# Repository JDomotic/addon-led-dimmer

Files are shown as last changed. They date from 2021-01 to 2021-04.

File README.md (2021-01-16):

# 9 Channel PWM Dimmer Addon
This is a custom made PWM dimmer addon which fits on the back of the [Wireless sensor board](https://github.com/JDomotic/esp12-wireless-sensor-board) .

The board can receive commands over uart with configurable transition speed per channel

## Version 1 | 05-01-2019
**Features**:
* Onboard 500ma 3.3v power regulator to power itself and the wireless sensor board
* Support for 12v led strips 
* 9 PWM channels 8 bit

**Schematic**

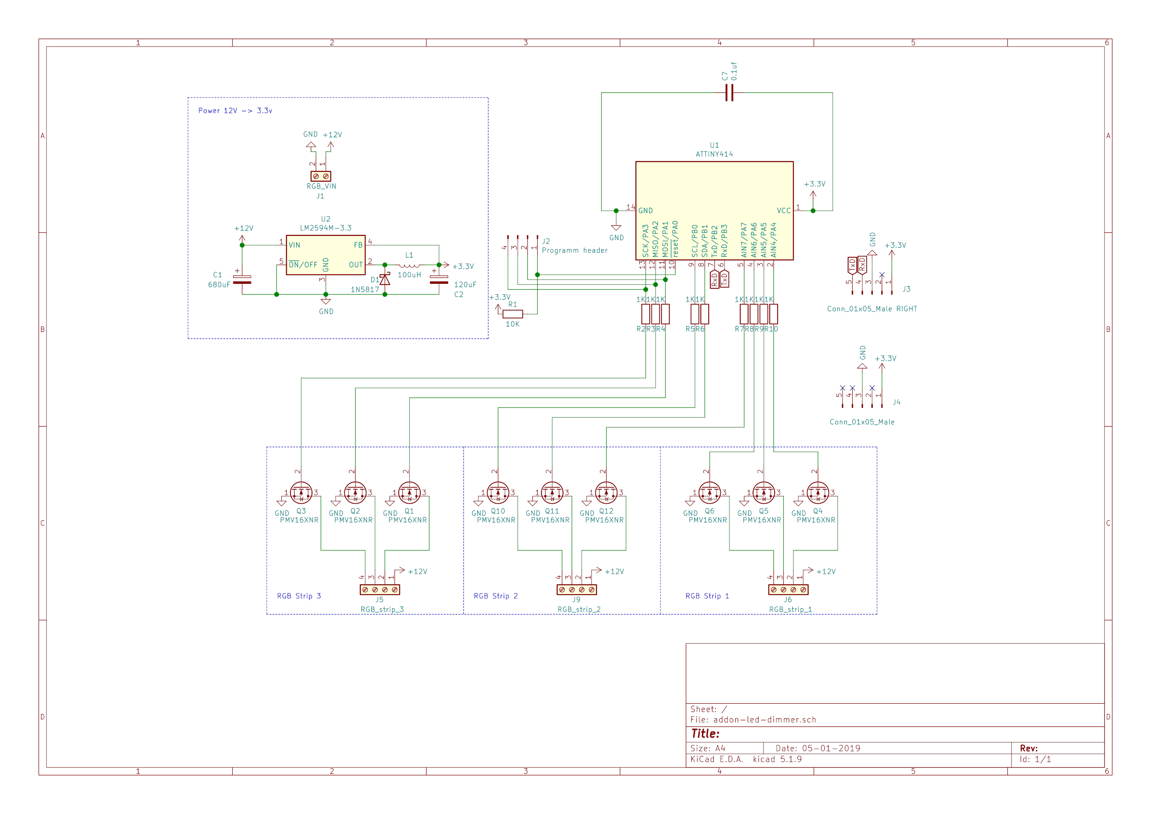
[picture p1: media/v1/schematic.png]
Schematic V1


**BOM**

**Ref**|**Qnty**|**Value**|**Footprint**|**Vendor (LCSC)**
:-----: | :-----: | :-----: | :-----: | :-----:
C1,|1|680uF|Capacitor\_THT:CP\_Radial\_D8.0mm\_P3.50mm|C59427|$0,0906
C2,|1|120uF|Capacitor\_THT:CP\_Radial\_D6.3mm\_P2.50mm|C251018|$0,1182
C7,|1|0.1uf|Capacitor\_SMD:C\_1206\_3216Metric\_Pad1.42x1.75mm\_HandSolder|C128353|$0,0179
D1,|1|1N5817|Diode\_THT:D\_DO-41\_SOD81\_P10.16mm\_Horizontal|C169165|$0,0223
J1,|1|RGB\_VIN|TerminalBlock\_Phoenix:TerminalBlock\_Phoenix\_MKDS-1,5-2\_1x02\_P5.00mm\_Horizontal|C8269|$0,0954
J3,|1|Conn\_01x05\_Male RIGHT|Connector\_PinHeader\_2.54mm:PinHeader\_1x05\_P2.54mm\_Vertical|-|0
J4,|1|Conn\_01x05\_Male|Connector\_PinHeader\_2.54mm:PinHeader\_1x05\_P2.54mm\_Vertical|-|0
J5,|2|RGB\_strip\_3|TerminalBlock\_Phoenix:TerminalBlock\_Phoenix\_MKDS-1,5-4\_1x04\_P5.00mm\_Horizontal|C8269|$0,1908
J6,|2|RGB\_strip\_1|TerminalBlock\_Phoenix:TerminalBlock\_Phoenix\_MKDS-1,5-4\_1x04\_P5.00mm\_Horizontal|C8269|$0,1908
J9,|2|RGB\_strip\_2|TerminalBlock\_Phoenix:TerminalBlock\_Phoenix\_MKDS-1,5-4\_1x04\_P5.00mm\_Horizontal|C8269|$0,1908
L1,|1|100uH|Inductor\_SMD:L\_6.3x6.3\_H3|C10122|$0,0731
Q1, Q2, Q3, Q4, Q5, Q6, Q10, Q11, Q12,|9|PMV16XNR|Package\_TO\_SOT\_SMD:SOT-23|C110920|$0,8064
R1,|1|10K|Resistor\_SMD:R\_0805\_2012Metric\_Pad1.15x1.40mm\_HandSolder|C103904|$0,0025
R2, R3, R4, R5, R6, R7, R8, R9, R10,|9|1K|Resistor\_SMD:R\_0805\_2012Metric\_Pad1.15x1.40mm\_HandSolder|C95781|$0,0360
U1,|1|ATTINY414|Package\_SO:SOIC-14\_3.9x8.7mm\_P1.27mm|C189365|$0,7137
U2,|1|LM2594M-3.3|Package\_SO:SOIC-8\_3.9x4.9mm\_P1.27mm|C316691|$0,6088

**Render**

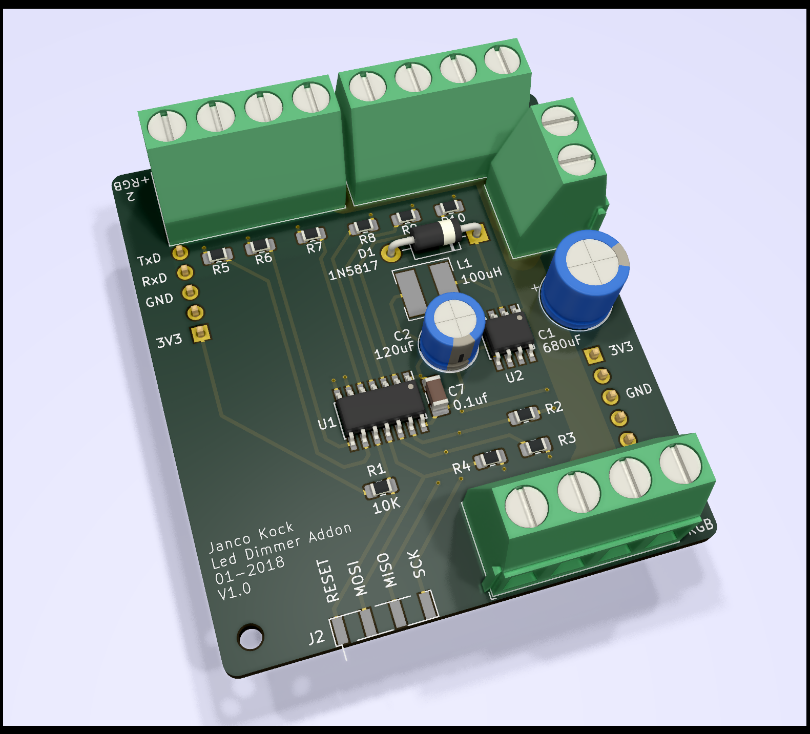
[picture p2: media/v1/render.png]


**Assembled**

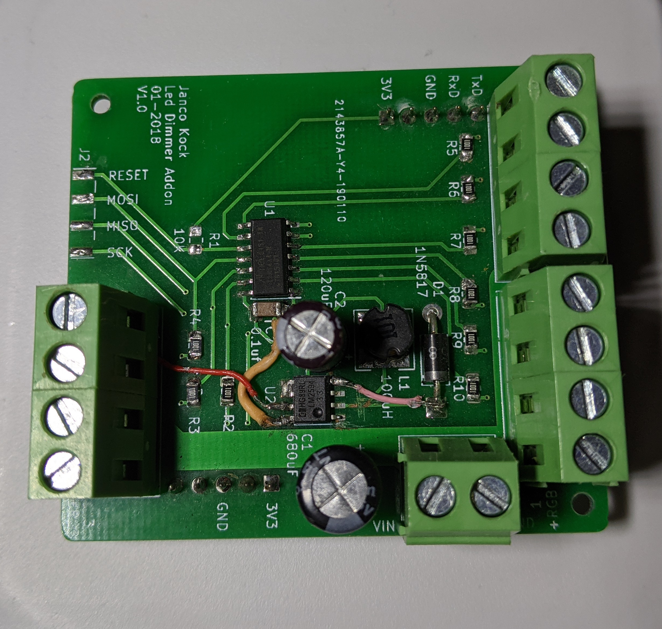
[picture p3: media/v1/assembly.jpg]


**Issues**

As vissible in the assembly, there are a few issues. 
1. The wrong SOT-23 footprint is used. Due this, the mosfets needs to be soldered upside down (This because pin 1 and 2 are flipped) 
2. The wrong pin layout for U2 is used. The trace to pad 1, 2 and 4 needs to be scratched. Pad 4 needs to be connected to D1, pad 8 to 3.3v and pad 7 to VIN.

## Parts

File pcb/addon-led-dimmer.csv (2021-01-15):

Source: | /home/janco/Documents/pcb/sensor_board_led/sensor_board-led.sch
Date: | Sat 09 Jan 2021 10:49:02 PM CET
Tool: | Eeschema 5.1.9
Generator: | /usr/share/kicad/plugins/bom_csv_grouped_by_value_with_fp.py
Component Count: | 33
Ref | Qnty | Value | Cmp name | Footprint | Description | Vendor
C1, | 1 | 680uF | CP | Capacitor_THT:CP_Radial_D8.0mm_P3.50mm | Polarized capacitor | C59427
C2, | 1 | 120uF | CP | Capacitor_THT:CP_Radial_D6.3mm_P2.50mm | Polarized capacitor | C251018
C7, | 1 | 0.1uf | C | Capacitor_SMD:C_1206_3216Metric_Pad1.42x1.75mm_HandSolder | Unpolarized capacitor
D1, | 1 | 1N5817 | 1N5820 | Diode_THT:D_DO-41_SOD81_P10.16mm_Horizontal | 20V 3A Schottky Barrier Rectifier Diode, DO-201AD | C169165
J1, | 1 | RGB_VIN | Screw_Terminal_01x02 | TerminalBlock_Phoenix:TerminalBlock_Phoenix_MKDS-1,5-2_1x02_P5.00mm_Horizontal | Generic screw terminal, single row, 01x02, script generated (kicad-library-utils/schlib/autogen/connector/) | C8269
J2, | 1 | Programm header | Conn_01x04_Male | Connector_PinHeader_2.54mm:PinHeader_1x04_P2.54mm_Vertical_SMD_Pin1Left | Generic connector, single row, 01x04, script generated (kicad-library-utils/schlib/autogen/connector/)
J3, | 1 | Conn_01x05_Male RIGHT | Conn_01x05_Male | Connector_PinHeader_2.54mm:PinHeader_1x05_P2.54mm_Vertical | Generic connector, single row, 01x05, script generated (kicad-library-utils/schlib/autogen/connector/)
J4, | 1 | Conn_01x05_Male | Conn_01x05_Male | Connector_PinHeader_2.54mm:PinHeader_1x05_P2.54mm_Vertical | Generic connector, single row, 01x05, script generated (kicad-library-utils/schlib/autogen/connector/)
J5, | 1 | RGB_strip_3 | Screw_Terminal_01x04 | TerminalBlock_Phoenix:TerminalBlock_Phoenix_MKDS-1,5-4_1x04_P5.00mm_Horizontal | Generic screw terminal, single row, 01x04, script generated (kicad-library-utils/schlib/autogen/connector/) | C8269*2
J6, | 1 | RGB_strip_1 | Screw_Terminal_01x04 | TerminalBlock_Phoenix:TerminalBlock_Phoenix_MKDS-1,5-4_1x04_P5.00mm_Horizontal | Generic screw terminal, single row, 01x04, script generated (kicad-library-utils/schlib/autogen/connector/) | C8269*2
J9, | 1 | RGB_strip_2 | Screw_Terminal_01x04 | TerminalBlock_Phoenix:TerminalBlock_Phoenix_MKDS-1,5-4_1x04_P5.00mm_Horizontal | Generic screw terminal, single row, 01x04, script generated (kicad-library-utils/schlib/autogen/connector/) | C8269*2
L1, | 1 | 100uH | L | Inductor_SMD:L_6.3x6.3_H3 | Inductor | C10122
Q1, Q2, Q3, Q4, Q5, Q6, Q10, Q11, Q12, | 9 | PMV16XNR | 2N7000 | Package_TO_SOT_SMD:SOT-23 | 0.2A Id, 200V Vds, N-Channel MOSFET, 2.6V Logic Level, TO-92 | C110920
R1, | 1 | 10K | R | Resistor_SMD:R_0805_2012Metric_Pad1.15x1.40mm_HandSolder | Resistor | C103904
R2, R3, R4, R5, R6, R7, R8, R9, R10, | 9 | 1K | R | Resistor_SMD:R_0805_2012Metric_Pad1.15x1.40mm_HandSolder | Resistor | C95781
U1, | 1 | ATTINY414 | ATTINY1614-SSFR | Package_SO:SOIC-14_3.9x8.7mm_P1.27mm | 12MHz, 16kB Flash, 1kB SRAM, 256B EEPROM, ADC, ACI, debugWIRE, SOIC-20 | C189365
U2, | 1 | LM2594M-3.3 | LM2596S-3.3 | Package_SO:SOIC-8_3.9x4.9mm_P1.27mm | 3.3V 3A Step-Down Voltage Regulator, TO-263 | C316691

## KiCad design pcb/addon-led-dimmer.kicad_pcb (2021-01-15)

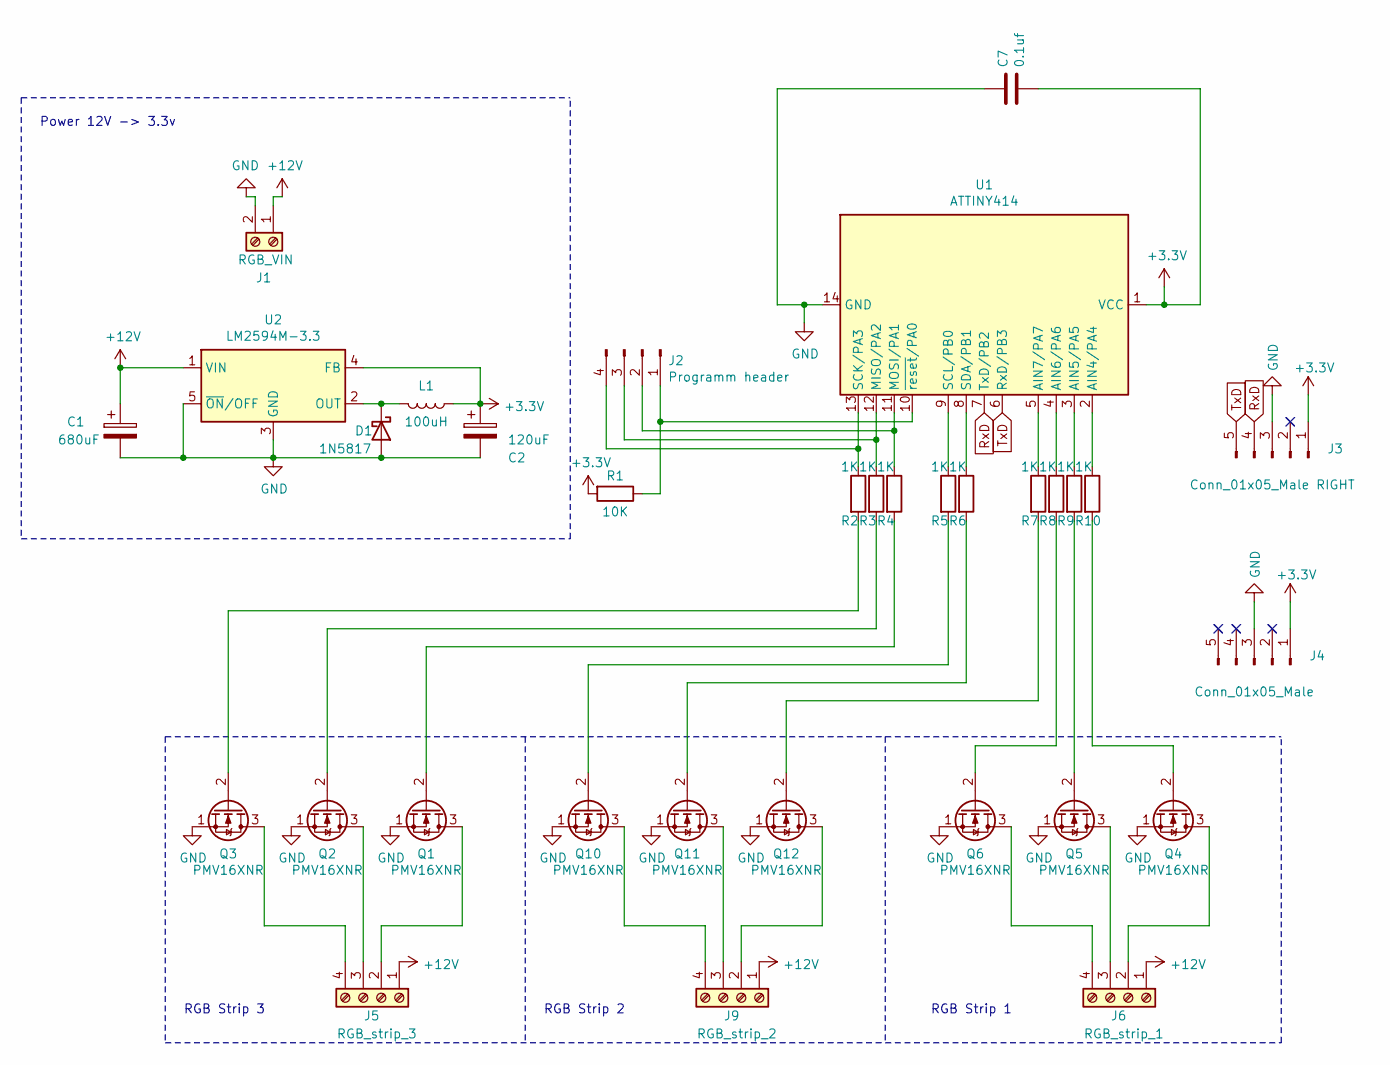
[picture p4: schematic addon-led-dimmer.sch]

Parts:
C1: 680uF; CP_Radial_D8.0mm_P3.50mm
C2: 120uF; CP_Radial_D6.3mm_P2.50mm
C7: 0.1uf; C_1206_3216Metric_Pad1.42x1.75mm_HandSolder
D1: 1N5817; D_DO-41_SOD81_P10.16mm_Horizontal
J1: RGB_VIN; TerminalBlock_Phoenix_MKDS-1,5-2_1x02_P5.00mm_Horizontal
J2: Programm header; PinHeader_1x04_P2.54mm_Vertical_SMD_Pin1Left
J3: Conn_01x05_Male RIGHT; PinHeader_1x05_P2.54mm_Vertical
J4: Conn_01x05_Male; PinHeader_1x05_P2.54mm_Vertical
J5: RGB_strip_3; TerminalBlock_Phoenix_MKDS-1,5-4_1x04_P5.00mm_Horizontal
J6: RGB_strip_1; TerminalBlock_Phoenix_MKDS-1,5-4_1x04_P5.00mm_Horizontal
J9: RGB_strip_2; TerminalBlock_Phoenix_MKDS-1,5-4_1x04_P5.00mm_Horizontal
L1: 100uH; L_6.3x6.3_H3
Q1, Q2, Q3, Q4, Q5, Q6, Q10, Q11, Q12: PMV16XNR; SOT-23
R1: 10K; R_0805_2012Metric_Pad1.15x1.40mm_HandSolder
R2, R3, R4, R5, R6, R7, R8, R9, R10: 1K; R_0805_2012Metric_Pad1.15x1.40mm_HandSolder
U1: ATTINY414; SOIC-14_3.9x8.7mm_P1.27mm
U2: LM2594M-3.3; SOIC-8_3.9x4.9mm_P1.27mm

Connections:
+3V3: C2.1, C7.2, J3.1, J4.1, L1.1, R1.2, U1.1 (VCC), U2.4 (FB)
+12V: C1.1, J1.1, J5.1, J6.1, J9.1, U2.1 (VIN)
GND: C1.2, C2.2, C7.1, D1.2 (A), J1.2, J3.3, J4.3, Q1.1 (S), Q2.1 (S), Q3.1 (S), Q4.1 (S), Q5.1 (S), Q6.1 (S), Q10.1 (S), Q11.1 (S), Q12.1 (S), U1.14 (GND), U2.3 (GND), U2.5 (~ON~/OFF)
unnamed: D1.1 (K), L1.2, U2.2 (OUT)
unnamed: J2.1, R1.1, U1.10 (~reset~/PA0)
unnamed: J2.2, R4.1, U1.11 (MOSI/PA1)
unnamed: J2.3, R3.1, U1.12 (MISO/PA2)
unnamed: J2.4, R2.1, U1.13 (SCK/PA3)
unnamed: J5.2, Q1.3 (D)
unnamed: J5.3, Q2.3 (D)
unnamed: J5.4, Q3.3 (D)
unnamed: J6.2, Q4.3 (D)
unnamed: J6.3, Q5.3 (D)
unnamed: J6.4, Q6.3 (D)
unnamed: J9.2, Q12.3 (D)
unnamed: J9.3, Q11.3 (D)
unnamed: J9.4, Q10.3 (D)
unnamed: Q1.2 (G), R4.2
unnamed: Q2.2 (G), R3.2
unnamed: Q3.2 (G), R2.2
unnamed: Q4.2 (G), R10.2
unnamed: Q5.2 (G), R9.2
unnamed: Q6.2 (G), R8.2
unnamed: Q10.2 (G), R5.2
unnamed: Q11.2 (G), R6.2
unnamed: Q12.2 (G), R7.2
unnamed: R5.1, U1.9 (SCL/PB0)
unnamed: R6.1, U1.8 (SDA/PB1)
unnamed: R7.1, U1.5 (AIN7/PA7)
unnamed: R8.1, U1.4 (AIN6/PA6)
unnamed: R9.1, U1.3 (AIN5/PA5)
unnamed: R10.1, U1.2 (AIN4/PA4)
RxD: J3.4, U1.7 (TxD/PB2)
TxD: J3.5, U1.6 (RxD/PB3)

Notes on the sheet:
Power 12V -> 3.3v
RGB Strip 1
RGB Strip 3
RGB Strip 2

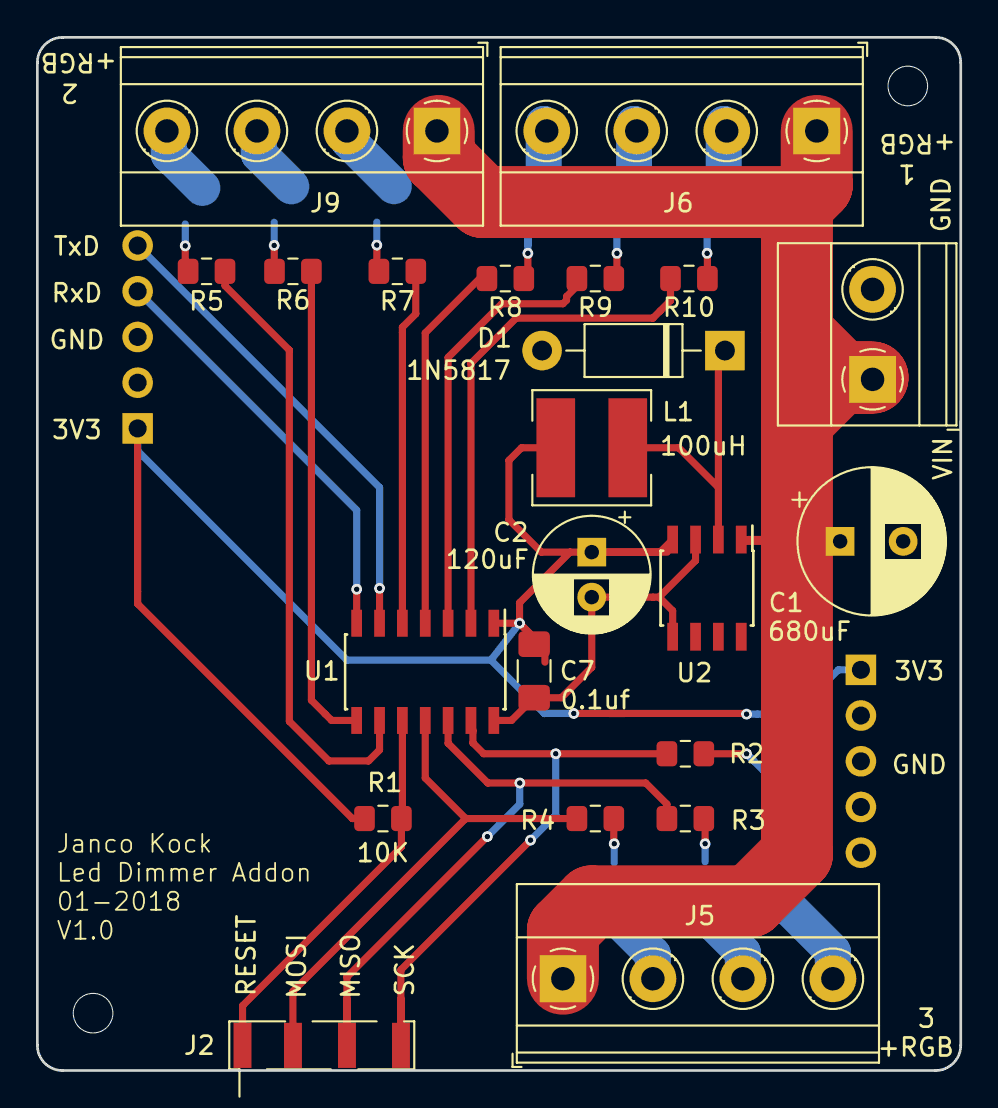
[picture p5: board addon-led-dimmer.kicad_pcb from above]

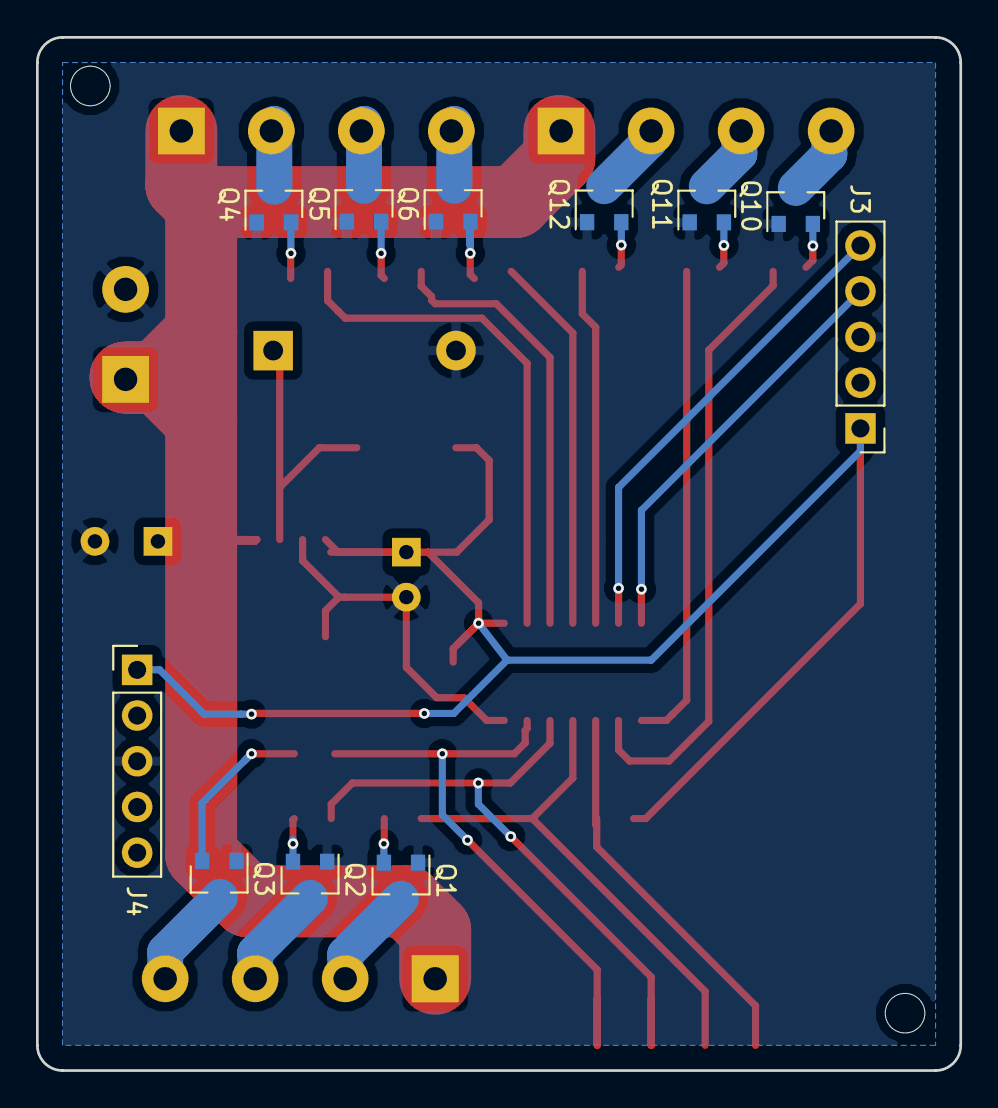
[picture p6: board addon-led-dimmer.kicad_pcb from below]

Board: 2 copper layers, 51.3 x 57.4 mm, 34 parts (11 on the bottom side), 34 nets.

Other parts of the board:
wREF**: MountingHole_2.2mm_M2_DIN965

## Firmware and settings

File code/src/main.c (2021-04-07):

/*
 * main.c
 *
 * Created: 20-1-2019 15:04:12
 * Author : Janco Kock
 */				
#define F_CPU 10000000UL
#define BAUD_RATE 115200
#define USART0_BAUD_RATE ((float)F_CPU * 64) / (16 * (float)BAUD_RATE)

#define LED_OUTPUT_SCALE 10000UL

#define IDENTIFIER 'O'

#include <avr/io.h>
#include <avr/interrupt.h>
#include <stdbool.h>
#include <string.h>
#include <stdio.h>

// UART methods
int8_t USART_init();
uint8_t USART_read();
void USART_write(const uint8_t data);
void printString(const char myString[]);

const uint8_t gamme8[256] = {
	128, 128, 128, 128, 128, 128, 128, 128, 128, 128, 128, 128, 128, 128, 128, 128, 128, 128, 128, 128,
	129, 129, 129, 129, 129, 129, 129, 129, 129, 129, 129, 129, 129, 129, 129, 129, 129, 129, 129, 129,
	130, 130, 130, 130, 130, 130, 130, 130, 130, 130, 130, 130, 130, 130, 130, 130, 130, 130, 130, 130,
	131, 131, 131, 131, 131, 131, 131, 131, 131, 131, 131, 131, 131, 131, 131, 131, 131, 131, 131, 131,
	132, 132, 132, 132, 132, 132, 132, 132, 132, 132, 132, 132, 132, 132, 132, 132, 132, 132, 132, 132,
	133, 133, 133, 133, 133, 133, 133, 133, 133, 133, 134, 134, 134, 134, 134, 134, 134, 134, 134, 134,
	135, 135, 135, 135, 135, 135, 135, 135, 135, 135, 136, 136, 136, 136, 136, 136, 136, 136, 136, 136,
	137, 137, 137, 137, 137, 137, 137, 137, 137, 137, 138, 138, 138, 138, 138, 138, 138, 138, 138, 138,
	139, 139, 139, 139, 139, 139, 140, 140, 140, 140, 140, 140, 141, 141, 141, 141, 141, 141, 141, 141,
	142, 142, 142, 142, 143, 143, 143, 143, 143, 144, 144, 144, 144, 144, 145, 145, 145, 145, 145, 145,
	146, 146, 146, 147, 147, 147, 148, 148, 148, 149, 149, 149, 150, 150, 150, 151, 151, 151, 152, 152,
	152, 153, 153, 153, 154, 154, 154, 155, 155, 155, 156, 156, 156, 157, 157, 158, 158, 159, 159, 160,
	160, 161, 162, 163, 164, 165, 166, 167, 168, 169, 170, 171, 172, 173, 174, 175
};

typedef struct tick_value {uint8_t tick; uint8_t LEDS_PORTA; uint8_t LEDS_PORTB;} tick_value;
tick_value port_output_values_0[10] = {0};
tick_value port_output_values_1[10] = {0};
tick_value *port_output_values = port_output_values_0;
uint8_t current_port_values = 0;

uint8_t port_output_value_index = 0;
uint8_t current_tick = 0;

uint8_t wanted_led_output_values[18];
long led_output_values[9] = {0};
	
uint8_t uart_led_channel = 0;
bool recalculate_port_output_values = false;

///
/// Timer A for software PWM
///
ISR(TCA0_OVF_vect){
	current_tick++;

	//Set top based on gamma correction 
	//TCA0_SINGLE_PER = gamme8[current_tick];
	
	if(current_tick == 0){
		port_output_value_index = 0;
		// Set correct output buffer
		if(current_port_values == 0){
			port_output_values = port_output_values_0;
		}else{
			port_output_values = port_output_values_1;
		}
	}

	if(current_tick == port_output_values[port_output_value_index].tick){
		PORTA_OUT = port_output_values[port_output_value_index].LEDS_PORTA; 
		PORTB_OUT = port_output_values[port_output_value_index].LEDS_PORTB;
		++port_output_value_index; 
	}

	// Clear interrupt flag
	TCA0_SINGLE_INTFLAGS = 0b00000001; 
} 

///
/// Timer B for UART package timeout check
///
ISR(TCB0_INT_vect){
	// Timeout between UART package occurs. Reset channel
	uart_led_channel = 0;
	// Disable
	TCB0_CTRLA = 0b00000010;
	// Clear interrupt flag
	TCB0_INTFLAGS = 0b00000001;
	// Write 'out of sync' package
	USART_write(IDENTIFIER);
}

///
/// UART methods
///
ISR(USART0_RXC_vect){
	wanted_led_output_values[uart_led_channel] =  USART0.RXDATAL;
	
	// Update package is done, so reset the UART package channel to 0
	if(uart_led_channel == 17){
		uart_led_channel = 0;
		
		recalculate_port_output_values = true;
		
		// Disable package timeout timer
		TCB0.CNT = 0;
		TCB0_CTRLA = 0b00000010;
	} else{
		uart_led_channel++;
		
		// Enable package timeout timer.
		TCB0.CNT = 0;
		TCB0_CTRLA = 0b00000011;
	}
}

uint8_t currentChannel = 0xff;
uint8_t byteNumber = 0x00;

static char isFirstByte = true; // to bypass the NACK flag for the first byte in a transaction
ISR(TWI0_TWIS_vect)
{

	if (TWI0.SSTATUS & TWI_COLL_bm) {
		//I2C_0_collision_callback();
		return;
	}

	if (TWI0.SSTATUS & TWI_BUSERR_bm) {
		//I2C_0_bus_error_callback();
		return;
	}

	if ((TWI0.SSTATUS & TWI_APIF_bm) && (TWI0.SSTATUS & TWI_AP_bm)) {
		//I2C_0_address_callback();
		// Write ACK callback here because otherwise the master won't receive an ACK when selecting the address
		byteNumber = 0;
		TWI0.SCTRLB = TWI_ACKACT_ACK_gc | TWI_SCMD_RESPONSE_gc; 
		isFirstByte = true;
		return;
	}

	if (TWI0.SSTATUS & TWI_DIF_bm) {
		if (TWI0.SSTATUS & TWI_DIR_bm) {
			// Master wishes to read from slave
			if (!(TWI0.SSTATUS & TWI_RXACK_bm) || isFirstByte) {
				// Received ACK from master or First byte of transaction
				isFirstByte = false;
				//I2C_0_read_callback();
				TWI0.SCTRLB = TWI_ACKACT_ACK_gc | TWI_SCMD_RESPONSE_gc;
			} else {
				// Received NACK from master
				// Reset module
				TWI0.SSTATUS |= (TWI_DIF_bm | TWI_APIF_bm);
				TWI0.SCTRLB = TWI_SCMD_COMPTRANS_gc;
			}
		} else // Master wishes to write to slave
		{
			uint8_t data = TWI0.SDATA;
			if(byteNumber == 0){ // Receive register/channel
				if(data < 18){
					currentChannel = data;
				}else{
					currentChannel = 0xFF;
					// Channel invalid. write NACK
					TWI0.SCTRLB = TWI_ACKACT_NACK_gc | TWI_SCMD_RESPONSE_gc; 
				}
				byteNumber++;
			}else if(byteNumber == 1){ // received data
				if(currentChannel != 0xFF)
					wanted_led_output_values[currentChannel] = data;
				byteNumber = 0;
			}
		}
		return;
	}

	// Check if STOP was received
	if ((TWI0.SSTATUS & TWI_APIF_bm) && (!(TWI0.SSTATUS & TWI_AP_bm))) {
		//I2C_0_stop_callback();
		recalculate_port_output_values = true;
		TWI0.SCTRLB = TWI_SCMD_COMPTRANS_gc;
		return;
	}
}

int8_t USART_init(){
	int8_t sigrow_val = SIGROW.OSC20ERR3V; // read signed error
	int32_t baud_reg_val = USART0_BAUD_RATE;
	baud_reg_val *= (1024 + sigrow_val); // sum resolution + error
	baud_reg_val /= 1024; // divide by resolution
	USART0.BAUD = (int16_t) baud_reg_val;
	
	// Enable receive interrupt 
	USART0.CTRLA = 0b10000000;
  
	USART0.CTRLB = 0 << USART_MPCM_bp       /* Multi-processor Communication Mode: disabled */
	| 0 << USART_ODME_bp     /* Open Drain Mode Enable: disabled */
	| 1 << USART_RXEN_bp     /* Receiver enable: enabled */
	| USART_RXMODE_NORMAL_gc /* Normal mode */
	| 0 << USART_SFDEN_bp    /* Start Frame Detection Enable: disabled */
	| 1 << USART_TXEN_bp;    /* Transmitter Enable: enabled */

	USART0.CTRLC = USART_CMODE_ASYNCHRONOUS_gc /* Asynchronous Mode */
	| USART_CHSIZE_8BIT_gc /* Character size: 8 bit */
	| USART_PMODE_DISABLED_gc /* No Parity */
	| USART_SBMODE_1BIT_gc; /* 1 stop bit */

	return 0;
}

uint8_t USART_read()
{
	while (!(USART0.STATUS & USART_RXCIF_bm));
	return USART0.RXDATAL;
}

void USART_write(const uint8_t data)
{
	while (!(USART0.STATUS & USART_DREIF_bm));
	USART0.TXDATAL = data;
}

void printString(const char myString[]) {
	uint8_t i = 0;
	while (myString[i]) {
		USART_write(myString[i]);
		i++;
	}
}


void calculate_steps(){
	uint8_t tmp;
	uint8_t steps[10];
	uint8_t output_values[9];
	
	tick_value *tmp_output;
	if(current_port_values == 0){
		tmp_output = port_output_values_1;
	}else{
		tmp_output = port_output_values_0;
	}
	
	// Copy led output values and convert them to uint8		
	steps[0] = 0;
	for(uint8_t i = 1; i < 10; i++){
		output_values[i-1] = ((led_output_values[i-1]) / LED_OUTPUT_SCALE);
		steps[i] = output_values[i-1];
	}
	
	// Sort steps
	uint8_t *steps_offset = &steps[1];
	for(uint8_t i = 0; i < 9; i++){
		for(uint8_t j = 0; j < (9-i-1); j++){
			if (steps_offset[j] > steps_offset[j + 1]){
				tmp = steps_offset[j];
				steps_offset[j] = steps_offset[j + 1];
				steps_offset[j + 1] = tmp;
			}
		}
	}
	
	tmp_output[0].tick = 0;
	tmp_output[0].LEDS_PORTB =  ((output_values[6] > 0) << 2) | ((output_values[7] > 0) << 3) | 								// Strip 3, connector 3, RG
																((output_values[1] > 0) << 1) | ((output_values[2] > 0) << 0);	// Strip 1, connector 2, GB		
	tmp_output[0].LEDS_PORTA =	((output_values[0] > 0) << 7) |																	// Strip 1, connector 2, R
								((output_values[5] > 0) << 6) | ((output_values[4] > 0) << 5) | ((output_values[3] > 0) << 4) | // Strip 2, connector 1, BGR
								((output_values[8] > 0) << 3); 																	// Strip 3, connector 3, B
	
	uint8_t index = 0;

	for(uint8_t i = 1; i < 10; i++){
		// Skip if step is the same as previous one
		if(steps[i] != steps[i - 1]){
			index++;
			tmp_output[index].tick = steps[i];
			tmp_output[index].LEDS_PORTB =	((output_values[1] > steps[i]) << 3) | ((output_values[2] > steps[i]) << 2);
			tmp_output[index].LEDS_PORTA =	((output_values[0] > steps[i]) << 7) |
											((output_values[5] > steps[i]) << 6) | ((output_values[4] > steps[i]) << 5) | ((output_values[3] > steps[i]) << 4) |
											((output_values[8] > steps[i]) << 3) | ((output_values[7] > steps[i]) << 2) | ((output_values[6] > steps[i]) << 1);
		}
	}
	
	// Set other values back to zero
	for(++index; index < 10; index++){
		tmp_output[index].tick = 0;
	}
	
	// Switch output buffer
	current_port_values = !current_port_values;
}

int main(void)
{
	///
	/// CPU clock settings
	///
	
	// Disable change protection
	CPU_CCP = 0xD8;
	
	// Set main pre-scaler division to 2 (so 20mhz / 2 = 10mhz)
	CLKCTRL_MCLKCTRLB = 0b00000001;
	
	// Lock the registers again
	CLKCTRL_MCLKLOCK = 1;
	
	// Set TX pin high
	PORTB_OUT = 0b00000100;
	
	// PB0 and PB1 output, RX and TX as output
	PORTB_DIR = 0b00001111;
	// PA1 - PA7 output
	PORTA_DIR = 0b11111110;
	
	//USART_init();	
	
	///
	/// Timer A for software PWM
	///
	
	// Timer A top 128
	TCA0_SINGLE_PER = 100; 
	// Enable timer A and set division to 2
	TCA0_SINGLE_CTRLA = 0b00000001;
	// Enable overflow interrupt
	TCA0_SINGLE_INTCTRL = 0b00000001; 
	
	///
	/// Timer B for UART package timeout check
	///
	
	// // Set tcb0 top
	// TCB0.CCMP = 0xffff;
	// // Set to timeout check mode
	// TCB0_CTRLB = 0b00000000;
	// // Enable interrupt
	// TCB0.INTCTRL = 0b00000001;

	//
	// Configure I2C
	//
	CPUINT_LVL1VEC = TCA0_OVF_vect;

	// Set I2C alternative pins
	PORTMUX_CTRLB |= PORTMUX_TWI0_bm;

	TWI0.SADDR = 0x20 << TWI_ADDRMASK_gp /* Slave Address: 0x20 */
	             | 0 << TWI_ADDREN_bp;   /* General Call Recognition Enable: disabled */

	TWI0.SCTRLA = 1 << TWI_APIEN_bp    /* Address/Stop Interrupt Enable: enabled */
	              | 1 << TWI_DIEN_bp   /* Data Interrupt Enable: enabled */
	              | 1 << TWI_ENABLE_bp /* Enable TWI Slave: enabled */
	              | 1 << TWI_PIEN_bp   /* Stop Interrupt Enable: enabled */
	              | 0 << TWI_PMEN_bp   /* Promiscuous Mode Enable: disabled */
	              | 1 << TWI_SMEN_bp;  /* Smart Mode Enable: disabled */
	TWI0.SCTRLA |= TWI_ENABLE_bm;	   // Enable
	
	// Enable all interrupt
	sei();
	
	uint8_t i;
	uint8_t fade_channel;
	
	long led_output_fade_steps_values[9] = {0};
	int led_output_fade_steps[9] = {0};
	bool need_to_recalculate = false;

	
	while(1){
		if(recalculate_port_output_values){
			recalculate_port_output_values = false;
			
			// Calculate the fade steps
			fade_channel = 8;
			for(i = 0; i < 9; i++){
				fade_channel++;
				
				long scaled_value = (wanted_led_output_values[i] * LED_OUTPUT_SCALE);
				long step_value =  (scaled_value - led_output_values[i]) /  (wanted_led_output_values[fade_channel] * 4);
				
				led_output_fade_steps_values[i] = step_value;
				
				led_output_fade_steps[i] = (wanted_led_output_values[fade_channel]*4);
			}
			continue;
		}
		need_to_recalculate = false;
		for(i = 0; i < 9; i++){
			if(led_output_fade_steps[i] != 0){
				led_output_fade_steps[i]--;
				led_output_values[i] += led_output_fade_steps_values[i];
				need_to_recalculate = true;
			}
		}
		if(need_to_recalculate)
			calculate_steps();
		continue;
	}
}

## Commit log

2021-01-16 Repository cleanup
    [sensor_board-led-B.Cu.gbr, sensor_board-led-B.Mask.gbr, sensor_board-led-B.SilkS.gbr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]
2021-01-16 Add readme Renamed kicad files
    [addon-led-dimmer.csv, addon-led-dimmer.kicad_pcb, addon-led-dimmer.sch]
2021-03-24 Implement I2C
2021-04-07 Change interface to I2C
    Repo cleanup
2024-02-18 Upgrade PCB project to KiCad 6 and bundle the ATtiny1614 symbol
